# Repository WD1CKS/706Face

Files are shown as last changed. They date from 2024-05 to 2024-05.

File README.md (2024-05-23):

# 706Face - An IC-706 Head Unit Emulator

This project is to develop a head unit emulator and replacement CAT system for the IC-706.

## Hardware

Firmware is being written for the Raspberry Pi Pico.

## Features

Planned feature list:
* Kenwood-style CAT on the USB stdio port
* Integrated FSK keyer
* Integrated CW keyer
* Custom designed control panel using consumer parts (ie: Cherry MX switches, arcade spinners, etc)
* Small LCD display
* Full functionality of stock head unit

## References

https://www.oz9aec.net/radios/ic-706/diy-remote-kit-for-the-ic-706-part-2-a-closer-look-at-the-protocol
https://ok1zia.nagano.cz/wiki/Front_panel_IC-706

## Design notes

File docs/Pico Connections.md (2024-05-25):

# Connections to the Pico
This documents all the connections that are planned for the Pico.

## Power

The 8VDC line almost certainly doesn't provide enough power to run everything
we plan, so we'll want to use the 13.8VDC output on the ACC port.  We'll want
to buck down to 5V, and drive the pico VSYS from that through a schottky diode.

## Head unit connector on radio

This is intended to be the primary interface and will hopefully be the only one
that is actually required.

| Connector Pin | Pico Pin | Comment |
|---|---|---|
| 1 (LRXD) | UART0 TX | Rig control  |
| 2 (LTXD) | UART0 RX | Rig status |
| 3 (8VDC) | GPIOx | Power state  |
| 8 (PWK) | GPIOx | Power switch |

## CI-V Connector

The CI-V control allows direct selection of modes and tuning steps, which can
require a long press on the front panel.  We don't really care about stuff the
rig sends though (but we may end up needing UART RX for collision/error
detection).  Depending on how well behaved the rig is, we may be able to detect
CI-V vs. head unit using the head unit handshake sequence.

| Connector Pin | Pico Pin | Comment |
|---|---|---|
| Tip (Data) | UART1 TX | Mode selection  |
| Tip (Data) | UART1 RX | Error detection |

## Radio connector in head unit

If pass-through mode is enabled, we won't be able to use the CI-V connection
above, but can pass everything through to a real head unit and keep them in
sync.  We can also potentially use the LCD for our own nefarious purposes.

| Connector Pin | Pico Pin | Comment |
|---|---|---|
| 1 (LRXD) | UART1 RX | Pass-through |
| 2 (LTXD) | UART1 TX | Pass-through |

## ACC connection

While we could access the FSK key line via the FSK jack, we're likely to be
taking our power from ACC anyway, so using the FSKK line allows us to save an
extra connection.

Hopefully, we can use a PIO for FSK.

| Connector Pin | Pico Pin | Comment |
|---|---|---|
| 10 (FSKK) | GPIOx | FSK Keyer |

## ELEC-KEY

The only way to send CW through the head unit cable is via the mic up/down
buttons, which uses the keyer and doesn't allow both on at the same time.

This means for CW, we need to connect to the CW jack.  Since we're there, may
as well connect both signals.

Hopefully, we can use a PIO for CW.

| Connector Pin | Pico Pin | Comment |
|---|---|---|
| TIP | GPIOx | dit/straight |
| RING | GPIOx | dah |

## Custom keypad

For individual keys, we will use a conventional GPIO key matrix.  For the main
tuning knob, we'll need two GPIOs for the argade spinner encoder.  For other
knobs, we can use the ADC lines to read potentiaometers, and one GPIO per pot
to select.

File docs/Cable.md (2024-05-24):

# Head Unit Cable Connection

## Connectors

The head unit uses a single row of eight pogo pins with approximately 0.95mm plunger diameter, at a 2mm pitch.
Male pins are on the radio, pads are on the head unit.

## Pinout

It appears that pin 1 is on the top of the radio, but this has not been verified yet.

| Pin | Signal | Description |
|-----|---|---|
| 1 | LRXD | Data from head unit to radio |
| 2 | LTXD | Data from radio to head unit |
| 3 | 8VDC | Power to head unit |
| 4 | AF | Receive audio to headphone jack |
| 5 | GND | Ground for everything except the mic |
| 6 | MIC | Microphone input |
| 7 | MICE | Microphone ground |
| 8 | PWK | Power button (active low) |

## Physical layer

LRXD and LRXD are both 19200 8N1 at TTL level.

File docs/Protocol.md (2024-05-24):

# Rig/Head Unit protocol

Aside from the power off handshake, all messages in either direction take the format: `FE cmd data FD`

Three data bytes are escaped:
| Byte | Sent as |
|---|---|
| `FD` | `FF 0D` |
| `FE` | `FF 0E` |
| `FF` | `FF 0F` |

All others are sent as-is.

## Head Unit to Radio

### `00` PTT

One byte of data.  Bit 0 indicates PTT state, bit 1 indicates if something is plugged into the headphone jack (ie: speaker mute).

### `01` Buttons 0

One byte of data, each bit represents the state of a single button.  Bit 5 is not used.

| Bit | Button |
|-----|---|
| 0 | F-1 |
| 1 | Menu |
| 2 | Tuner/Call |
| 3 | P.Amp/ATT  |
| 4 | RIT/Sub |
| 6 | Mic Down |
| 7 | Mic Up |

### `02` Buttons 1

One byte of data, each bit represents the state of a single button.

| Bit | Button  |
|-----|---|
| 0 | Down |
| 1 | Up |
| 2 | TS |
| 3 | Mode |
| 4 | Lock |
| 5 | Display |
| 6 | F-3 |
| 7 | F-2 |

### `03` Tune

One byte of data `00` to `FF`, indicating main tune knob position.  Increments with clockwise rotation.

### `05` Volume

As above for Volume knob.

### `06` RF/SQL

As above for RF/SQL knob.

### `07` M-CH

As above for M-CH knob.

### `08` Shift

As above for Shift knob.

### `0B` Keepalive

A keepalive packet with a data byte of `00` must be sent periodically.
If one is not sent for 200ms, the radio shuts itself off.

The stock head unit sends the message every 100ms.

## Radio to Head Unit

### `60` Display Data

Data to display.  Format is not yet reverse engineered.

## Handshakes

There are two different handshakes for the radio.

### Power on

On a power on, the radio will repeatedly send `FE F0 FD` until the head unit replies with the same message.  Once it does, the radio will send `FE F1 FD` and the head unit is expected to echo this back as well.

### Power off

The radio sends a single `00` byte, and the head unit does as well.

## References

https://www.oz9aec.net/radios/ic-706/diy-remote-kit-for-the-ic-706-part-2-a-closer-look-at-the-protocol
https://ok1zia.nagano.cz/wiki/Front_panel_IC-706

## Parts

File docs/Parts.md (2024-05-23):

# Parts lists

## Prototype Sniffer Cable

This cable will go between the stock head unit and the radio for the purposes of reverse-engineering the protocol.
A 3D printed mount and custom PCB are likely to be needed.

Pogo pin array (2mm pitch) through-hole
https://www.digikey.com/en/products/detail/mill-max-manufacturing-corp/836-22-008-10-001101/6573073
Pad size: 1.68mm

Pogo pin array (2mm pitch) SMD
https://www.digikey.com/en/products/detail/preci-dip/821-S1-008-30-012101/5414108
Pad size: 1.5mm

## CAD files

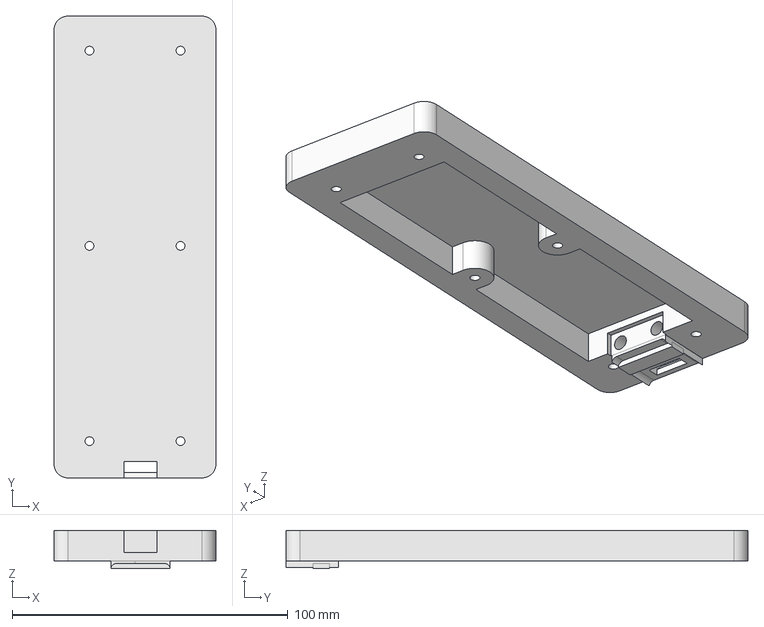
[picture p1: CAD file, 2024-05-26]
CAD/Radio End connector.FCStd
58.7 x 167.3 x 13.8 mm

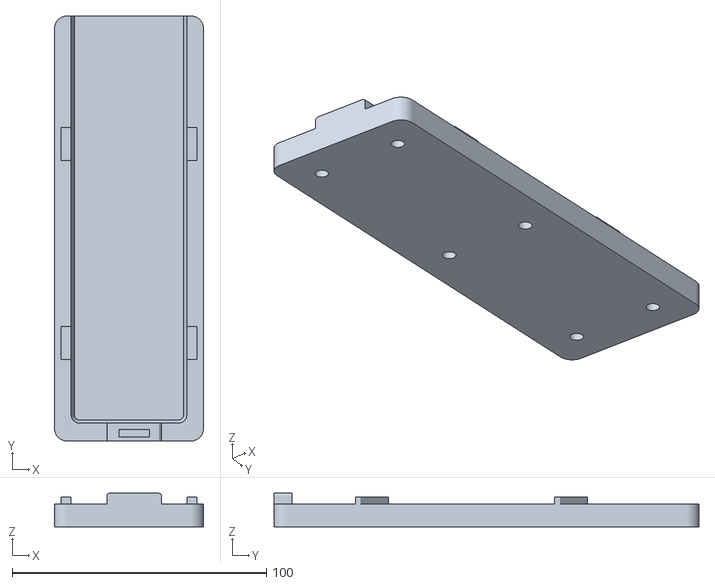
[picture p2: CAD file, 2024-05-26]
STLs/Radio End connector-Pass-through Plate.stl
58.7 x 167.3 x 13.2

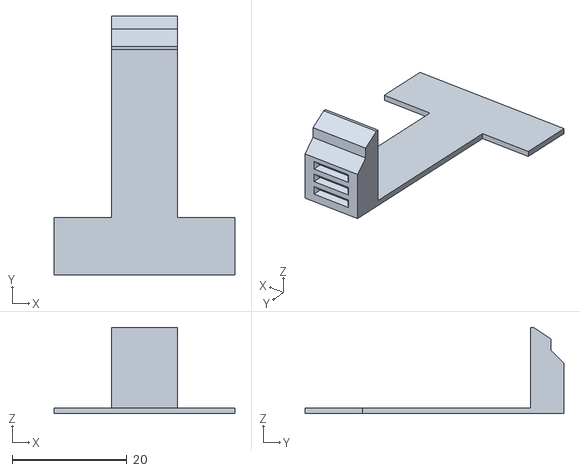
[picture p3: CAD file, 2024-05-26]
STLs/Radio End connector-Latch.stl
31.5 x 45.0 x 15.0

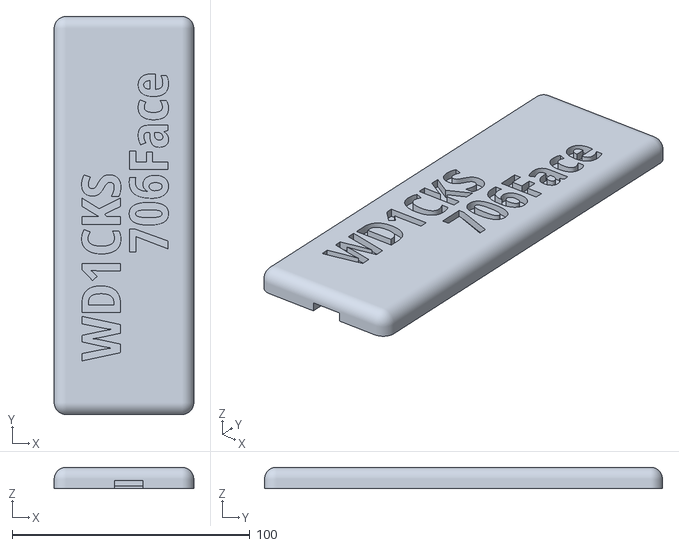
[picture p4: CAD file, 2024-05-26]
STLs/Radio End connector-Top Dress Plate.stl
58.7 x 167.3 x 9.00

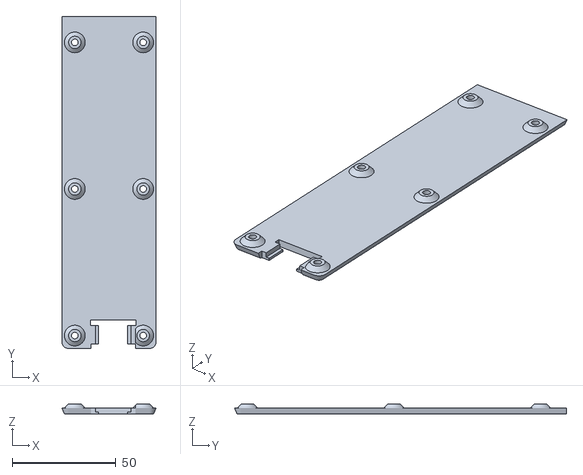
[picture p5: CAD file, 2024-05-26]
STLs/Radio End connector-Bottom Plate.stl
45.5 x 160.2 x 5.00

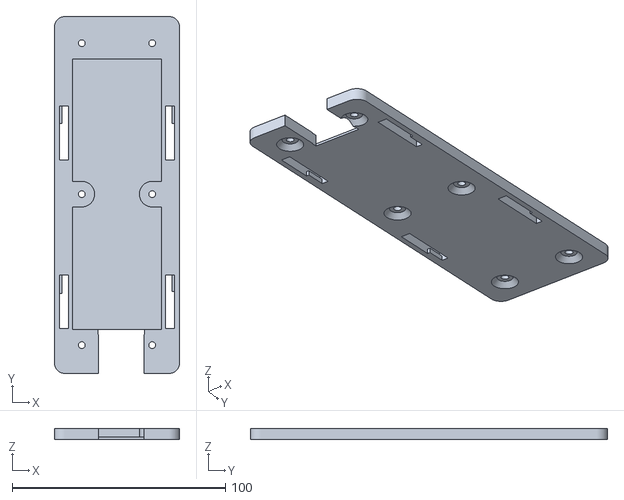
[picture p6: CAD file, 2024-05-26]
STLs/Radio End connector-Clip Plate.stl
58.7 x 167.3 x 5.00

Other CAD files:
STLs/Radio End connector-Board Mount.stl

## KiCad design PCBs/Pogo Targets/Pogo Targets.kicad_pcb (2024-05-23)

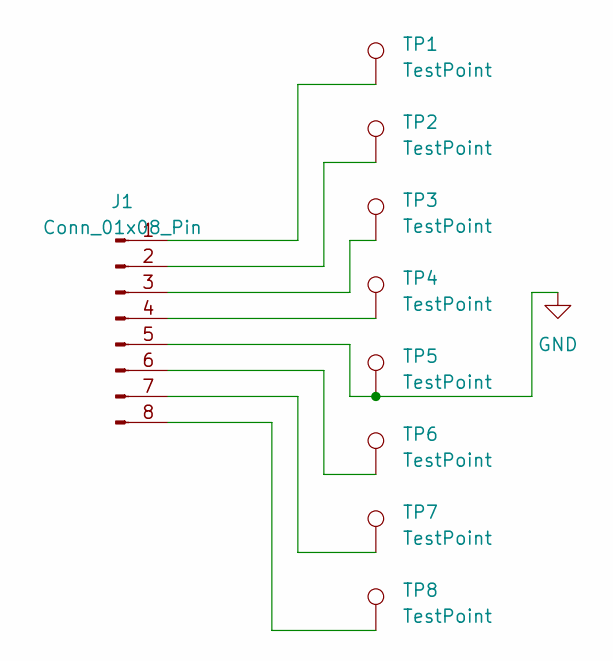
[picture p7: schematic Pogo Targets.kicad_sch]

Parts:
J1: Conn_01x08_Pin; PinHeader_1x08_P2.54mm_Vertical
TP1, TP2, TP3, TP4, TP5, TP6, TP7, TP8: TestPoint; TestPoint_Pad_D1.5mm

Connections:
GND: J1.5, TP5.1
unnamed: J1.1, TP1.1
unnamed: J1.2, TP2.1
unnamed: J1.3, TP3.1
unnamed: J1.4, TP4.1
unnamed: J1.6, TP6.1
unnamed: J1.7, TP7.1
unnamed: J1.8, TP8.1

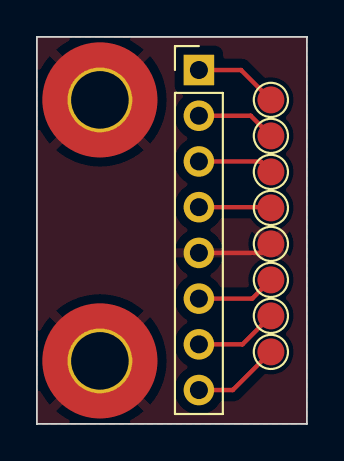
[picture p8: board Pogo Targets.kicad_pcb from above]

Board: 2 copper layers, 15.0 x 21.5 mm, 9 parts (0 on the bottom side), 8 nets.

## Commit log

2024-05-23 Add summary of references
    In case the web sites go away.
2024-05-23 Add some boilerplate and initial hackery
    Currently does nopthing forever.
2024-05-23 Document the connector as well.
2024-05-23 Add KiCad for Pogo Targets
    [Pogo Targets.kicad_pcb, Pogo Targets.kicad_sch]
2024-05-23 Ignore STEP files in PCBs too
    So I can 3D print them to prototype fitment.
2024-05-24 Ignore _autosave- from kicad as well.
2024-05-24 Start CADding up some stuff.
    [Radio End connector.FCStd]
2024-05-24 Some fitment tweaks.
    Bottom piece didn't engage fully, top plate hole spacing was off.
    [Radio End connector.FCStd]
2024-05-24 Some notes on how to connect the pico
2024-05-24 Add section on power
2024-05-25 Fiddle with clips, add the rest of the parts.
    Still need to figure out board mounting, but we should really have
    boards before we do that.
    [Radio End connector.FCStd]
2024-05-26 Final tweakage... can not be printed and assembled.
    Still needs PCB mounts and cable strain relief.
    [Radio End connector.FCStd]
2024-05-26 Add initial STLs.
    This was used for prototype fitment, no cable strain relief or PCB
    mount posts yet.
    [Radio End connector-Board Mount.stl, Radio End connector-Bottom Plate.stl, Radio End connector-Clip Plate.stl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]
2024-05-26 Fix part orientation for printing.
    [Radio End connector-Board Mount.stl, Radio End connector-Latch.stl]
2024-05-26 Start of the pass-through plate.
    Does not yet have the pogo pins to make the electrical connection.
    [Radio End connector-Pass-through Plate.stl]
